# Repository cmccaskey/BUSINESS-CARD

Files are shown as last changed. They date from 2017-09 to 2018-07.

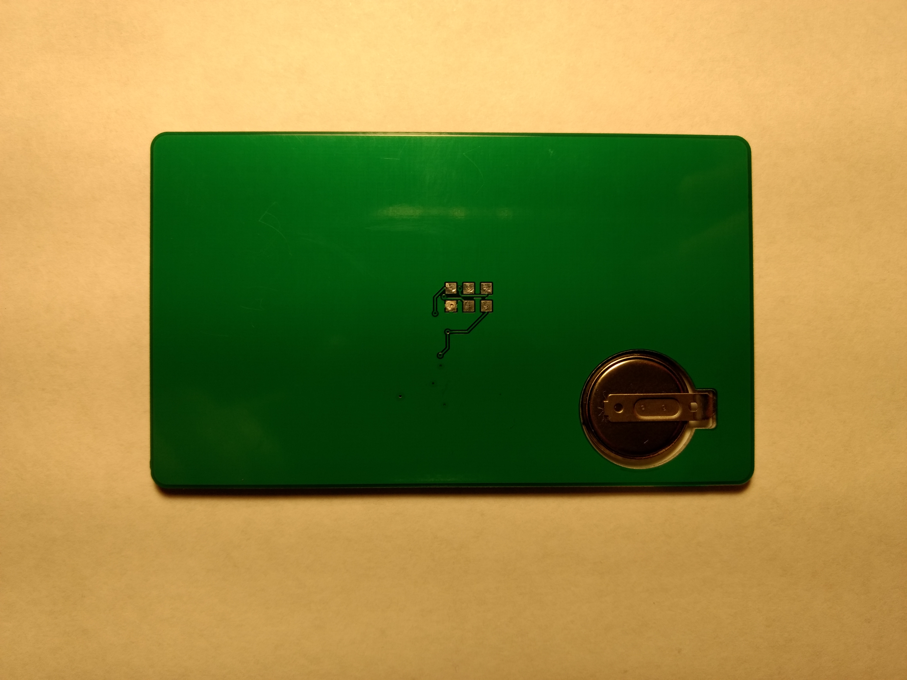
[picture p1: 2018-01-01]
IMAGES/BC Back.jpg

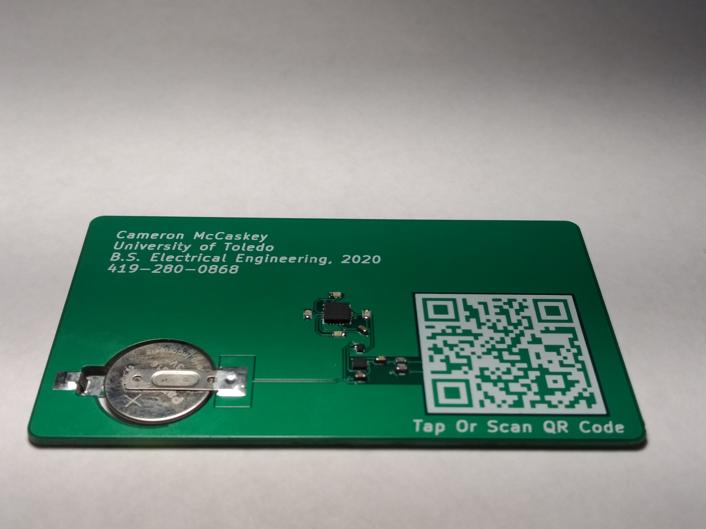
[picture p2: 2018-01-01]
IMAGES/BC Side.jpg

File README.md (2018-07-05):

# About #
This is a busness card I designed for a career fair that was held at my University. This card utilizes the ATtiny24A microcontroller and the AT42qt1011 Q-Touch IC.

image goes here

# Hardware History #

## REV C ## 
- This is an updated version of the board that uses a coin cell battery with the solder tabs welded on from the factory. This has proven to be more reliable than the previous self designed battery holder
- This version also included an inverter IC to generate the low level interrupt by hardware directly.
- The ground plane was added back on the bottom side of the PCB to make the card only sensitive to touch on the top side

# Firmware History #

## BC.c ##
- This is the code for the first two versions of the card

## TC.c ##
- This is the code for the third version that utilizes the hardware interrupt

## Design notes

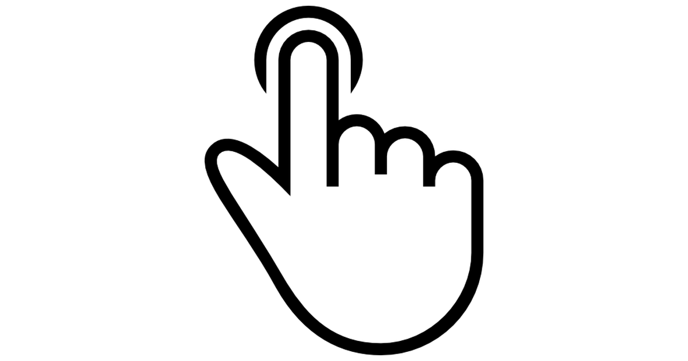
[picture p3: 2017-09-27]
HARDWARE/MOD/TOUCH_SYM.png

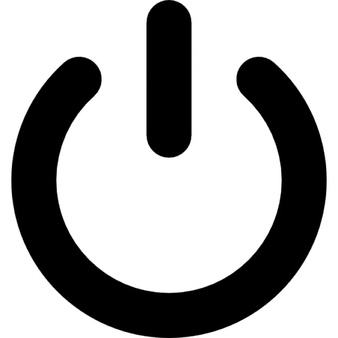
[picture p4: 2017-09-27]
HARDWARE/MOD/POWER.jpg

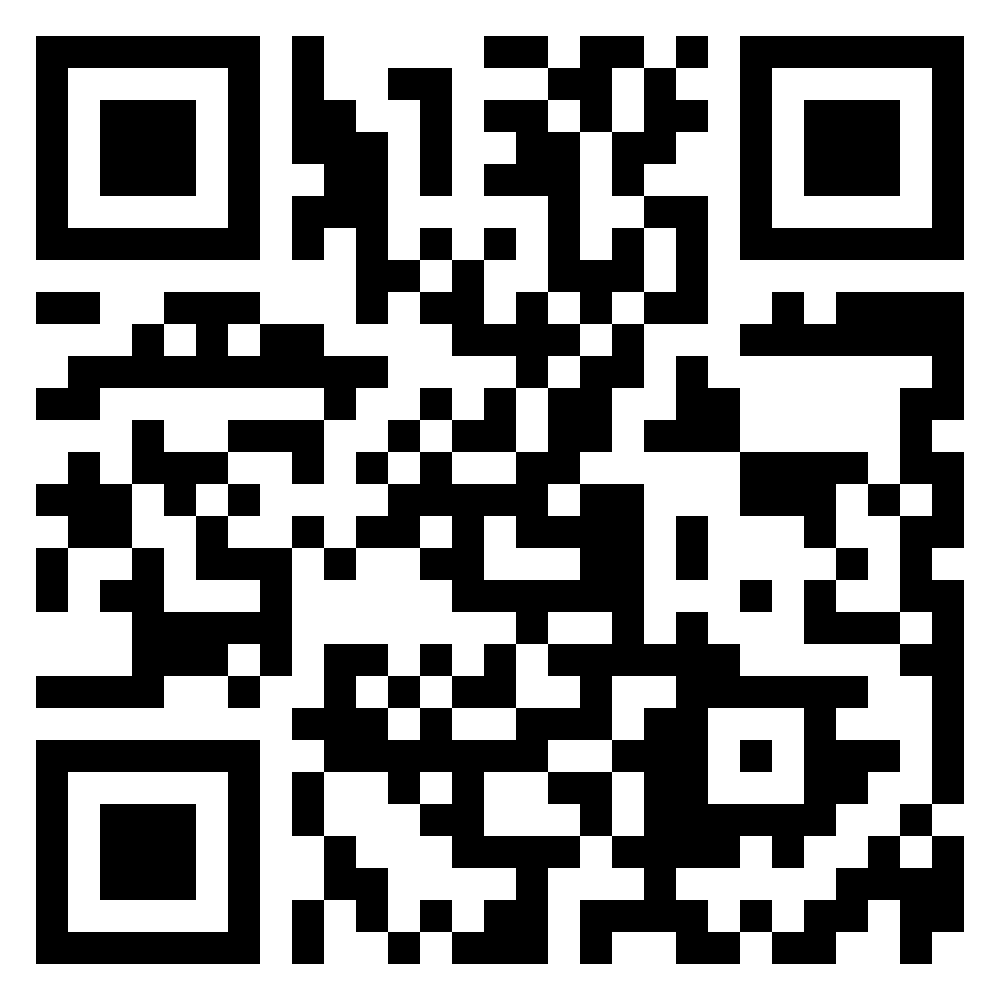
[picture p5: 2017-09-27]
HARDWARE/MOD/QR.png

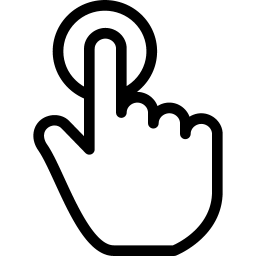
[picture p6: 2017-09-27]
HARDWARE/MOD/TOUCH_SYM.bmp

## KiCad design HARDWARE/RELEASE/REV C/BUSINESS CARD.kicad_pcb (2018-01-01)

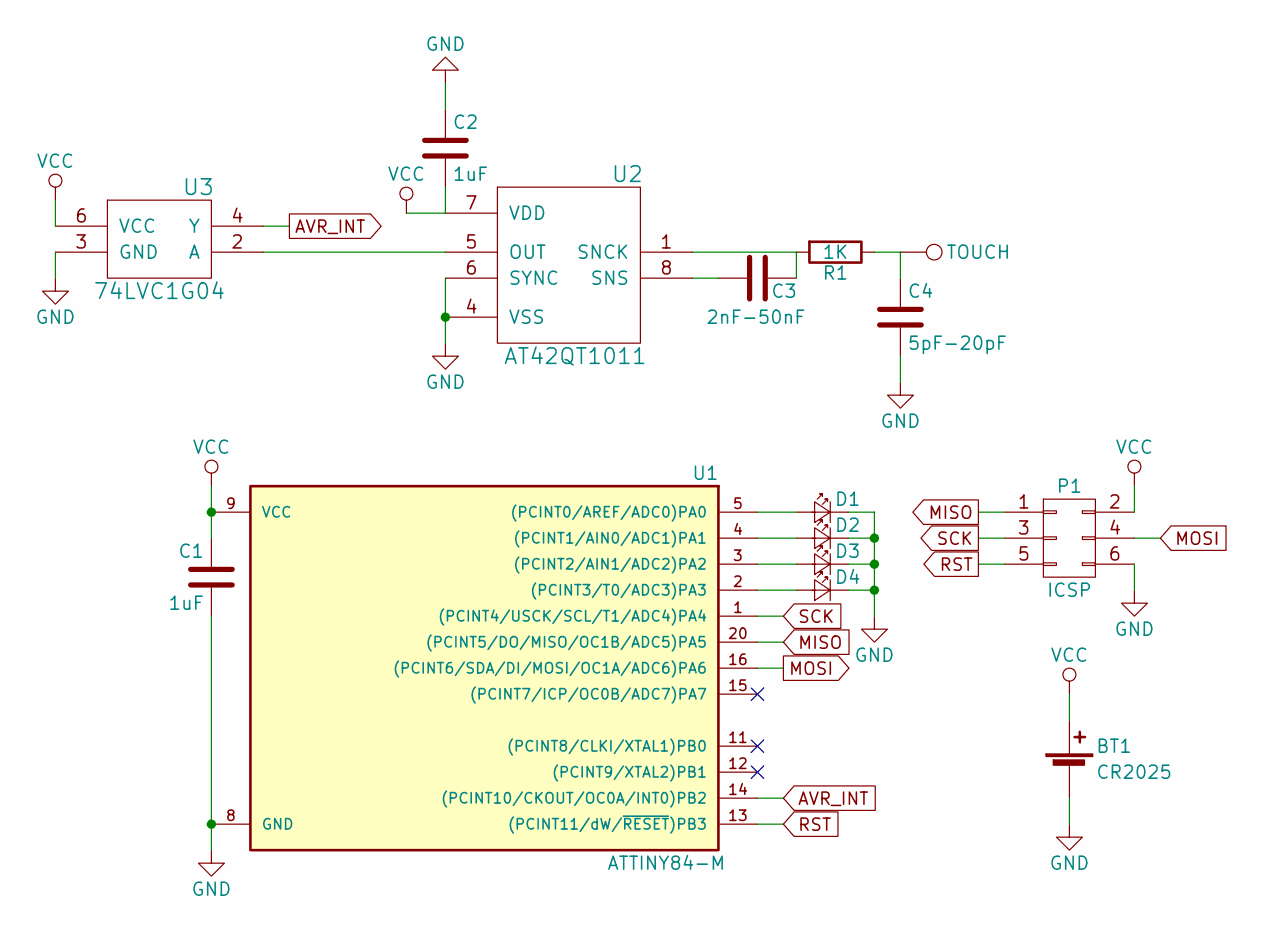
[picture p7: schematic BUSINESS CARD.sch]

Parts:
BT1: CR2025; CR-1616_F2N
C1, C2: 1uF; C_0603
C3: 2nF-50nF; C_0603
C4: 5pF-20pF; C_0603
D1, D2, D3, D4: LED_Small; LED_0603
P1: ICSP; 2.54 ICSP
R1: 1K; R_0603
T1: TOUCH
U1: ATTINY84-M; QFN-20-1EP_4x4mm_Pitch0.5mm
U2: AT42QT1011; DFN-8-1EP_2x2mm_Pitch0.5mm
U3: 74LVC1G04; DFN_1410_6

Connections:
AVR_INT: U1.14 ((PCINT10/CKOUT/OC0A/INT0)PB2), U3.4 (Y)
GND: BT1.2 (-), C1.2, C2.1, C4.2, D1.1 (K), D2.1 (K), D3.1 (K), D4.1 (K), P1.6, U1.8 (GND), U1.21, U2.4 (VSS), U2.6 (SYNC), U2.9, U3.3 (GND)
MISO: P1.1, U1.20 ((PCINT5/DO/MISO/OC1B/ADC5)PA5)
MOSI: P1.4, U1.16 ((PCINT6/SDA/DI/MOSI/OC1A/ADC6)PA6)
unnamed: C3.1, R1.2, U2.1 (SNCK)
unnamed: C3.2, U2.8 (SNS)
unnamed: C4.1, R1.1, T1.1
unnamed: D1.2 (A), U1.5 ((PCINT0/AREF/ADC0)PA0)
unnamed: D2.2 (A), U1.4 ((PCINT1/AIN0/ADC1)PA1)
unnamed: D3.2 (A), U1.3 ((PCINT2/AIN1/ADC2)PA2)
unnamed: D4.2 (A), U1.2 ((PCINT3/T0/ADC3)PA3)
unnamed: U2.5 (OUT), U3.2 (A)
RST: P1.5, U1.13 ((PCINT11/dW/~RESET~)PB3)
SCK: P1.3, U1.1 ((PCINT4/USCK/SCL/T1/ADC4)PA4)
VCC: BT1.1 (+), C1.1, C2.2, P1.2, U1.9 (VCC), U2.7 (VDD), U3.6 (VCC)

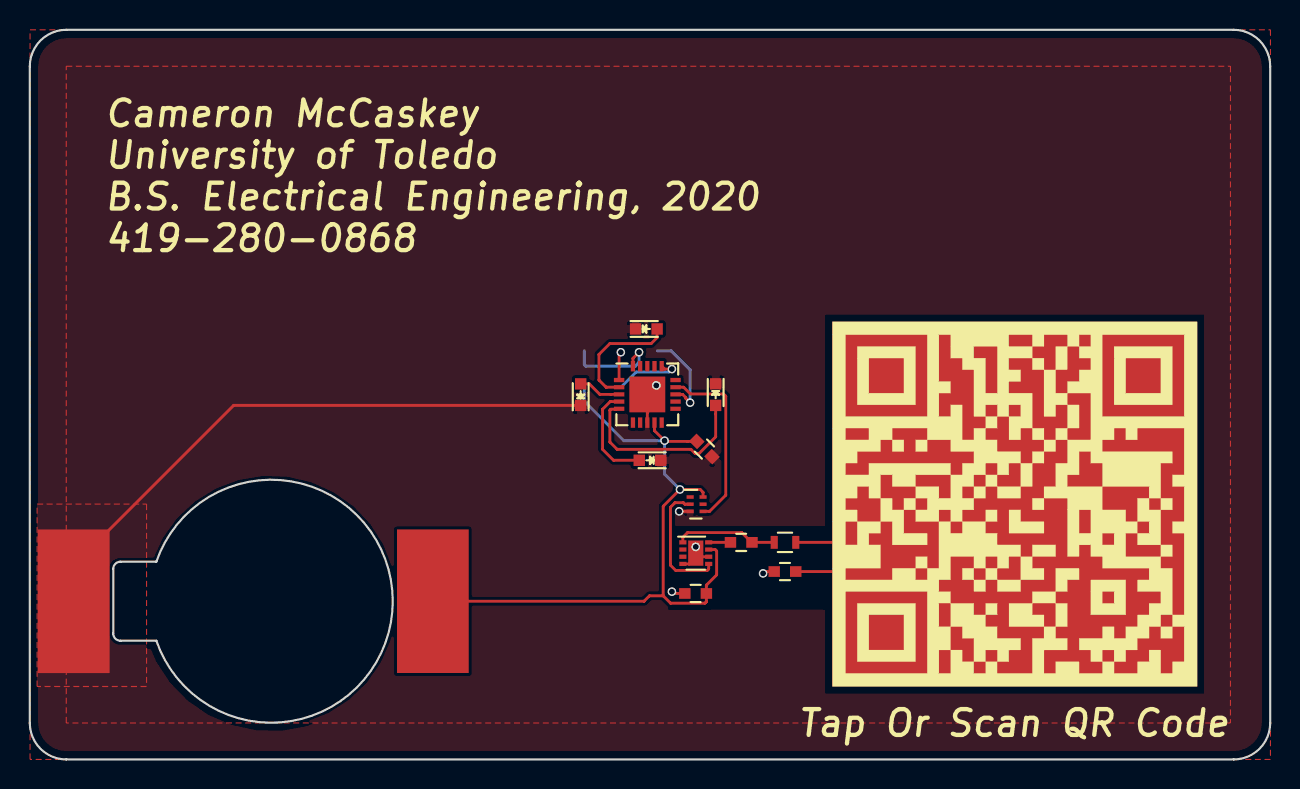
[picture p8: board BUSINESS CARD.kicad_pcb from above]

Board: 2 copper layers, 86.4 x 50.8 mm, 15 parts (1 on the bottom side), 15 nets.

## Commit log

2017-09-27 Initial Commit
    REV B fixes footprint for Q Touch IC. REV B includes new layout for card.
    [BUSINESS CARD.csv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]
2018-01-01 folder changes
    [BUSINESS CARD.csv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]
2018-07-04 removed old rev
    [BUSINESS CARD.csv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]
2018-07-04 update of gitignore
    [BUSINESS CARD.csv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]
